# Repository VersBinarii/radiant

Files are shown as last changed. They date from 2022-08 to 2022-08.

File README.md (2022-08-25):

# Radiant
Touch screen controlled light dimmer

# What is it
The dimming of light bulb it triggered by a touch screen.
It's a Leading-Edge dimmer so it should work even with modern led light bulbs that
are not dimmable in practice

# Schematics
Check the schematics folder for the Ki-Cad schematics and board design

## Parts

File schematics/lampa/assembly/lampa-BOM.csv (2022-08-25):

Comment | Designator | Footprint | LCSC
4.7uF | C1 | Capacitor_SMD:C_0402_1005Metric | C23733
20pF | C9,C10,C13,C14 | Capacitor_SMD:C_0402_1005Metric | C1554
2.2uF | C11,C12 | Capacitor_SMD:C_0603_1608Metric | C23630
100nF | C15 | Capacitor_SMD:C_0603_1608Metric | C14663
100nF | C2,C3,C4,C5 | Capacitor_SMD:C_0402_1005Metric | C1525
1uF | C6 | Capacitor_SMD:C_0402_1005Metric | C52923
10nF | C7 | Capacitor_SMD:C_0402_1005Metric | C15195
10uF | C8 | Capacitor_SMD:C_1206_3216Metric | C13585
LED BLUE | D1 | LED_SMD:LED_0603_1608Metric | C72041
LED GREEN | D2 | LED_SMD:LED_0603_1608Metric | C72043
Fuse | F1 | Fuse:Fuseholder_Cylinder-5x20mm_Stelvio-Kontek_PTF78_Horizontal_Open
MountingHole_Pad | H1,H2,H3,H4 | MountingHole:MountingHole_4.3mm_M4_Pad_Via
Screw_Terminal_01x02 | J1,J2 | TerminalBlock:TerminalBlock_bornier-2_P5.08mm
Conn_01x14 | J3 | Connector_PinHeader_2.54mm:PinHeader_1x14_P2.54mm_Vertical
Conn_01x04 | J4,J5 | Connector_PinHeader_2.54mm:PinHeader_1x04_P2.54mm_Vertical
39nH | L1 | Inductor_SMD:L_0402_1005Metric | C26443
HLK-PM12 | PS1 | Converter_ACDC:Converter_ACDC_HiLink_HLK-PMxx
IRF740 | Q1,Q2 | Package_TO_SOT_THT:TO-220-3_Vertical
S8050 | Q3 | Package_TO_SOT_SMD:SOT-23 | C2146
47 | R1 | Resistor_SMD:R_0402_1005Metric | C25118
4.7K | R9,R10 | Resistor_SMD:R_0402_1005Metric
10K | R11 | Resistor_SMD:R_0402_1005Metric | C25744
47K | R2,R3 | Resistor_SMD:R_0603_1608Metric | C25819
10K | R4 | Resistor_SMD:R_0603_1608Metric | C25804
22K | R5 | Resistor_SMD:R_0402_1005Metric | C25768
2K | R6 | Resistor_SMD:R_0402_1005Metric | C4109
680 | R7,R8 | Resistor_SMD:R_0603_1608Metric | C23228
SW_SPST | SW1 | Connector_PinSocket_2.54mm:PinSocket_1x02_P2.54mm_Vertical
SW_SPDT | SW2 | Connector_PinHeader_2.54mm:PinHeader_1x03_P2.54mm_Vertical
AMS1117-3.3 | U1 | Package_TO_SOT_SMD:SOT-223-3_TabPin2 | C6186
LTV-814 | U2 | Package_DIP:DIP-4_W7.62mm
4N35 | U3 | Package_DIP:SMDIP-6_W9.53mm_Clearance8mm
STM32F411CEUx | U4 | Package_DFN_QFN:QFN-48-1EP_7x7mm_P0.5mm_EP5.6x5.6mm | C60420
16MHz | Y1 | Crystal:Crystal_SMD_3225-4Pin_3.2x2.5mm | C9006
Crystal | Y2 | Crystal:Crystal_SMD_3215-2Pin_3.2x1.5mm | C32346

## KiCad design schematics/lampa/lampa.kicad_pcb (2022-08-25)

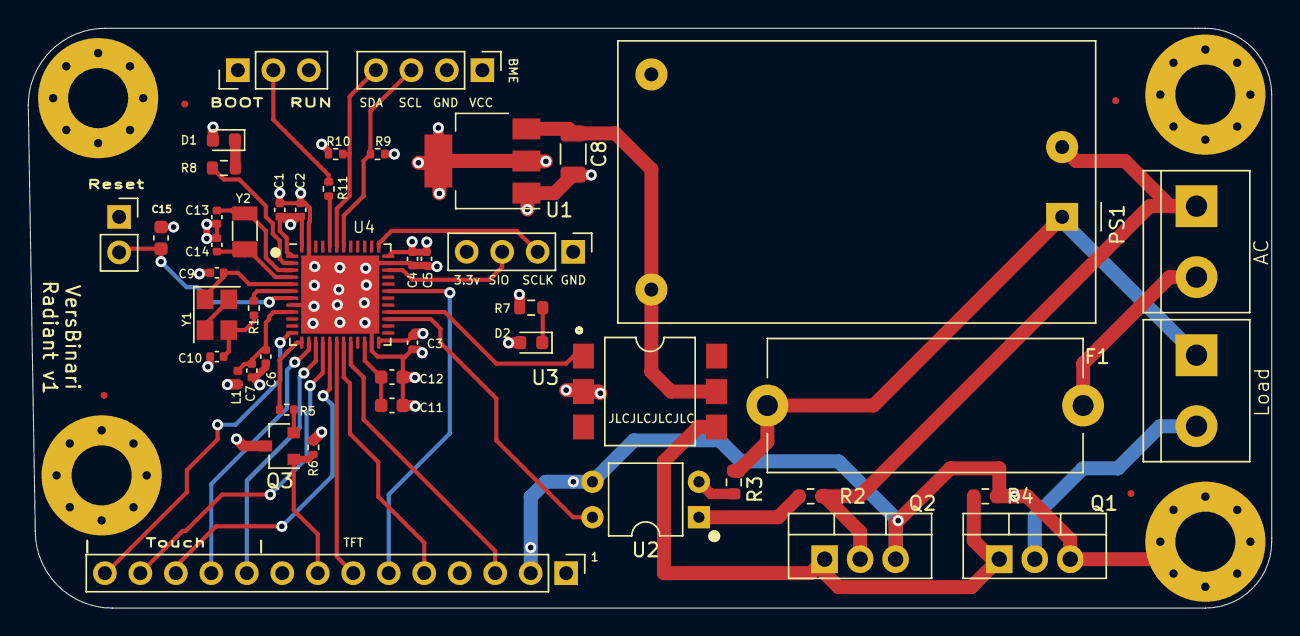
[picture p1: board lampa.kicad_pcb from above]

Board: 4 copper layers, 89.0 x 41.5 mm, 51 parts (0 on the bottom side), 42 nets.

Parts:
C1: 4.7uF; C_0402_1005Metric
C2, C3, C4, C5: 100nF; C_0402_1005Metric
C6: 1uF; C_0402_1005Metric
C7: 10nF; C_0402_1005Metric
C8: 10uF; C_1206_3216Metric
C9, C10, C13, C14: 20pF; C_0402_1005Metric
C11, C12: 2.2uF; C_0603_1608Metric
C15: 100nF; C_0603_1608Metric
D1: LED BLUE; LED_0603_1608Metric
D2: LED GREEN; LED_0603_1608Metric
F1: Fuse; Fuseholder_Cylinder-5x20mm_Stelvio-Kontek_PTF78_Horizontal_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
H1, H2, H3, H4: MountingHole_Pad; MountingHole_4.3mm_M4_Pad_Via
J1, J2: Screw_Terminal_01x02; TerminalBlock_bornier-2_P5.08mm
J3: Conn_01x14; PinHeader_1x14_P2.54mm_Vertical
J4, J5: Conn_01x04; PinHeader_1x04_P2.54mm_Vertical
L1: 39nH; L_0402_1005Metric
PS1: HLK-PM12; Converter_ACDC_HiLink_HLK-PMxx
Q1, Q2: IRF740; TO-220-3_Vertical
Q3: S8050; SOT-23
R1: 47; R_0402_1005Metric
R2, R3: 47K; R_0603_1608Metric
R4: 10K; R_0603_1608Metric
R5: 22K; R_0402_1005Metric
R6: 2K; R_0402_1005Metric
R7, R8: 680; R_0603_1608Metric
R9, R10: 4.7K; R_0402_1005Metric
R11: 10K; R_0402_1005Metric
SW1: SW_SPST; PinSocket_1x02_P2.54mm_Vertical
SW2: SW_SPDT; PinHeader_1x03_P2.54mm_Vertical
U1: AMS1117-3.3; SOT-223-3_TabPin2
U2: LTV-814; DIP-4_W7.62mm
U3: 4N35; SMDIP-6_W9.53mm_Clearance8mm
U4: STM32F411CEUx; QFN-48-1EP_7x7mm_P0.5mm_EP5.6x5.6mm
Y1: 16MHz; Crystal_SMD_3225-4Pin_3.2x2.5mm
Y2: Crystal; Crystal_SMD_3215-2Pin_3.2x1.5mm

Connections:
+3.3VA: C6.1, C7.1, L1.2, U4.9
+3V3: C1.1, C2.1, C3.1, C4.1, C5.1, D1.2, D2.2, J3.1, J3.4, J4.4, J5.1, L1.1, Q3.3, R9.1, R10.1, SW2.1, U1.2, U4.1, U4.24, U4.36, U4.48
+12V: C8.1, PS1.3, U1.3, U3.5
BACKLIGHT_PWM: R5.2, U4.13
BLUE_LED: R8.1, U4.2
BME_SCL: J5.3, R9.2, U4.42
BME_SDA: J5.4, R10.2, U4.43
BOOT: R11.2, U4.44
GND: C1.2, C2.2, C3.2, C4.2, C5.2, C6.2, C7.2, C8.2, C9.2, C10.2, C11.2, C12.2, C13.2, C14.2, C15.2, H1.1, H2.1, H3.1, H4.1, J3.2, J4.1, J5.2, PS1.4, Q1.3, Q2.3, R4.2, R6.1, R7.1, SW1.1, SW2.3, U1.1, U2.3, U3.2, U4.8, U4.23, U4.35, U4.47, U4.49
HSE_IN: C9.1, U4.5, Y1.1
HSE_OUT: R1.1, U4.6
LCD_CLK: J3.7, U4.18
LCD_CS: J3.3, U4.20
LCD_DC: J3.5, U4.19
LCD_MOSI: J3.6, U4.31
LSE_IN: C13.1, U4.3, Y2.1
LSE_OUT: C14.1, U4.4, Y2.2
NRST: C15.1, SW1.2, U4.7
unnamed: C10.1, R1.2, Y1.3
unnamed: C11.1, C12.1, U4.22
unnamed: D1.1, R8.2
unnamed: D2.1, R7.2
unnamed: F1.1, J1.2
unnamed: F1.2, J2.1, PS1.1, R3.1
unnamed: J1.1, PS1.2, Q2.2, R2.1
unnamed: J2.2, Q1.2
unnamed: J3.8, Q3.1, R6.2
unnamed: Q1.1, Q2.1, R4.1, U3.4
unnamed: Q3.2, R5.1
unnamed: R2.2, U2.1
unnamed: R3.2, U2.2
unnamed: R11.1, SW2.2
unnamed: Y1.2, Y1.4
SWCLK: J4.2, U4.37
SWDIO: J4.3, U4.34
TOUCH_CLK: J3.10, U4.15
TOUCH_CS: J3.11, U4.14
TOUCH_IRQ: J3.14, U4.12
TOUCH_MISO: J3.13, U4.16
TOUCH_MOSI: J3.12, U4.17
TRIAK_CTRL: U3.1, U4.28
ZERO_CROSS_DETECT: U2.4, U4.27

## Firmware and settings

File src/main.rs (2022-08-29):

#![no_main]
#![no_std]

use radiant as _;

#[rtic::app(device = stm32f4xx_hal::pac, dispatchers=[OTG_FS_WKUP, SDIO])]
mod app {
    use embedded_graphics::{pixelcolor::Rgb565, prelude::*};
    use radiant::{
        gui::{Button, Gui, GuiElement},
        peripherals::{
            init_preipherals, BlueLedPin, Lcd, TouchDriver, TriakControlPin, ZeroCrossDetectPin,
        },
    };
    use stm32f4xx_hal::{
        pac::{EXTI, TIM1},
        prelude::*,
        timer::{Delay, SysEvent},
    };

    #[shared]
    struct Shared {
        xpt_drv: TouchDriver,
        exti: EXTI,
        gui: Gui,
    }

    #[local]
    struct Local {
        blue_led: BlueLedPin,
        delay: Delay<TIM1, 1000000>,
        lcd: Lcd,
        zero_crossing: ZeroCrossDetectPin,
        triak_ctrl: TriakControlPin,
    }

    #[init]
    fn init(ctx: init::Context) -> (Shared, Local, init::Monotonics) {
        let cp = ctx.core;

        let (clocks, blue_led, zero_crossing, triak_ctrl, mut lcd, mut xpt_drv, mut delay, exti) =
            init_preipherals(ctx.device).unwrap();
        /*
         * Indicator that stuff is running
         */
        let mut systic = cp.SYST.counter_hz(&clocks);
        systic.start(1.kHz()).unwrap();
        systic.listen(SysEvent::Update);

        let _ = lcd.clear(Rgb565::BLUE);

        xpt_drv.init(&mut delay);
        let button_up = Button::new("+", Point::new(10, 10), Size::new(45, 45), Rgb565::MAGENTA);
        let button_down = Button::new("-", Point::new(60, 10), Size::new(45, 45), Rgb565::MAGENTA);

        (
            Shared {
                xpt_drv,
                exti,
                gui: Gui {
                    button_up,
                    button_down,
                },
            },
            Local {
                blue_led,
                delay,
                lcd,
                zero_crossing,
                triak_ctrl,
            },
            init::Monotonics(),
        )
    }

    #[idle(local = [delay], shared = [xpt_drv, exti,gui])]
    fn maintask(ctx: maintask::Context) -> ! {
        let mut xpt_drv = ctx.shared.xpt_drv;
        let _exti = ctx.shared.exti;
        let _delay = ctx.local.delay;
        let mut gui = ctx.shared.gui;

        render::spawn().ok();
        loop {
            xpt_drv.lock(|xpt| {
                if xpt.is_touched() {
                    let p = xpt.get_touch_point();
                    gui.lock(|g| {
                        g.button_up.update(&p);
                        g.button_down.update(&p);
                        if g.button_up.is_pressed() {
                            defmt::println!("up pressed");
                        }
                        if g.button_down.is_pressed() {
                            defmt::println!("down pressed");
                        }
                    });
                    render::spawn().ok();
                }
            });
        }
    }

    #[task(priority=3, local = [lcd], shared = [gui])]
    fn render(mut ctx: render::Context) {
        let lcd = ctx.local.lcd;
        ctx.shared.gui.lock(|g| {
            g.draw(lcd).expect("Error while rendering Gui");
        })
    }

    #[task(binds = EXTI2, local = [], shared = [xpt_drv, exti])]
    fn exti2(ctx: exti2::Context) {
        let xpt = ctx.shared.xpt_drv;
        let exti = ctx.shared.exti;
        (xpt, exti).lock(|xpt, exti| xpt.exti_irq_handle(exti))
    }

    #[task(binds = EXTI15_10, local = [zero_crossing, triak_ctrl], shared = [])]
    fn zero_crossing(ctx: zero_crossing::Context) {}

    #[task(local = [], shared = [])]
    fn triak_control(ctx: triak_control::Context) {}

    #[task(binds = SysTick, local = [counter:u16 = 0, blue_led], shared = [xpt_drv, exti])]
    fn systick(ctx: systick::Context) {
        let xpt = ctx.shared.xpt_drv;
        let exti = ctx.shared.exti;
        (xpt, exti).lock(|xpt, exti| xpt.run(exti));

        let counter = ctx.local.counter;
        *counter += 1;

        if *counter == 100 {
            ctx.local.blue_led.toggle();
            *counter = 0;
        }
    }
}

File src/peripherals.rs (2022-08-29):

use crate::dummy_pin::{DummyOutputPin, MyIrq};
use display_interface_spi::SPIInterface;
use ili9341::{DisplaySize240x320, Ili9341, Orientation};
use stm32f4xx_hal::{
    gpio::{Alternate, Edge, Input, NoPin, Output, Pin, PushPull},
    pac::{Peripherals, EXTI, SPI1, SPI5, TIM1},
    prelude::*,
    rcc::Clocks,
    spi::{Mode, NoMiso, Phase, Polarity, Spi},
    timer::{Channel, Delay},
};
use xpt2046::{self, Xpt2046};

/*
 * Touch driver interface
 * Controlled through the SPI 1 instance
 */
pub type TouchSpi = Spi<
    SPI1,
    (
        Pin<'A', 5, Alternate<5>>,
        Pin<'A', 6, Alternate<5>>,
        Pin<'A', 7, Alternate<5>>,
    ),
>;
pub type TouchDriver = Xpt2046<TouchSpi, Pin<'A', 4, Output<PushPull>>, MyIrq<'A', 2>>;

/*
 * LCD driver interface
 * Controlled through the SPI 5 instance
 */
pub type Lcd = Ili9341<
    SPIInterface<
        Spi<SPI5, (Pin<'B', 0, Alternate<6>>, NoPin, Pin<'A', 10, Alternate<6>>)>,
        Pin<'B', 1, Output>,
        Pin<'B', 2, Output>,
    >,
    DummyOutputPin,
>;

/*
 * Blue system led indicating system status
 */
pub type BlueLedPin = Pin<'C', 13, Output<PushPull>>;

/*
 *  Pin used for detection of the AC zeto crossing.
 *  Its connected to the LTV-814 opto coupler directly.
 *  Goes low whenever AC crosses the 0V.
 */
pub type ZeroCrossDetectPin = Pin<'B', 14, Input>;

/*
 * Used for driving the Triaks.
 * Connected directly to the 4N35 opto
 */
pub type TriakControlPin = Pin<'B', 15, Output<PushPull>>;

/*
 * TODO: Define error
 */
#[allow(clippy::type_complexity, clippy::result_unit_err)]
pub fn init_preipherals(
    mut dp: Peripherals,
) -> Result<
    (
        Clocks,
        BlueLedPin,
        ZeroCrossDetectPin,
        TriakControlPin,
        Lcd,
        TouchDriver,
        Delay<TIM1, 1000000>,
        EXTI,
    ),
    (),
> {
    let rcc = dp.RCC.constrain();
    let clocks = rcc.cfgr.use_hse(25.MHz()).sysclk(100.MHz()).freeze();

    let gpioa = dp.GPIOA.split();
    let gpiob = dp.GPIOB.split();
    let gpioc = dp.GPIOC.split();

    /*
     * We need a backlight control
     * TODO: We will need to be able to change the brighntess later
     */
    let backlight_pins = gpioa.pa3.into_alternate();
    let mut pwm = dp.TIM2.pwm_hz(backlight_pins, 10.kHz(), &clocks);
    pwm.enable(Channel::C4);
    pwm.set_duty(Channel::C4, pwm.get_max_duty() / 2);

    let blue_led = gpioc.pc13.into_push_pull_output();
    /*
     *  The ILI9341 driver
     */
    let lcd_clk = gpiob.pb0.into_alternate();
    let lcd_miso = NoMiso {};
    let lcd_mosi = gpioa.pa10.into_alternate().internal_pull_up(true);
    let lcd_dc = gpiob.pb1.into_push_pull_output();
    let lcd_cs = gpiob.pb2.into_push_pull_output();
    let mode = Mode {
        polarity: Polarity::IdleLow,
        phase: Phase::CaptureOnFirstTransition,
    };
    let lcd_spi = dp
        .SPI5
        .spi((lcd_clk, lcd_miso, lcd_mosi), mode, 8.MHz(), &clocks);
    let spi_iface = SPIInterface::new(lcd_spi, lcd_dc, lcd_cs);
    let dummy_reset = DummyOutputPin::default();
    let mut delay = dp.TIM1.delay_us(&clocks);
    let lcd = Ili9341::new(
        spi_iface,
        dummy_reset,
        &mut delay,
        Orientation::PortraitFlipped,
        DisplaySize240x320,
    )
    .unwrap();
    // Touch interface
    let mut touch_irq = gpioa.pa2.into_pull_up_input();
    let mut syscfg = dp.SYSCFG.constrain();
    touch_irq.make_interrupt_source(&mut syscfg);
    touch_irq.trigger_on_edge(&mut dp.EXTI, Edge::Falling);
    touch_irq.enable_interrupt(&mut dp.EXTI);
    let touch_cs = gpioa.pa4.into_push_pull_output();
    let touch_clk = gpioa.pa5.into_alternate();
    let touch_mosi = gpioa.pa7.into_alternate().internal_pull_up(true);
    let touch_miso = gpioa.pa6.into_alternate();
    let touch_spi = Spi::new(
        dp.SPI1,
        (touch_clk, touch_miso, touch_mosi),
        mode,
        4.MHz(),
        &clocks,
    );

    let xpt_drv = Xpt2046::new(
        touch_spi,
        touch_cs,
        MyIrq(touch_irq),
        xpt2046::Orientation::PortraitFlipped,
    );

    let mut zero_crossing = gpiob.pb14.into_pull_up_input();
    zero_crossing.make_interrupt_source(&mut syscfg);
    zero_crossing.trigger_on_edge(&mut dp.EXTI, Edge::Falling);
    zero_crossing.enable_interrupt(&mut dp.EXTI);
    let triak_ctrl = gpiob.pb15.into_push_pull_output();

    Ok((
        clocks,
        blue_led,
        zero_crossing,
        triak_ctrl,
        lcd,
        xpt_drv,
        delay,
        dp.EXTI,
    ))
}

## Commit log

2022-04-20 Working but requires calibration fix
    [main.rs]
2022-08-25 Lets press some buttons
2022-08-25 Add PCB scematics
    [lampa-BOM.csv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]
